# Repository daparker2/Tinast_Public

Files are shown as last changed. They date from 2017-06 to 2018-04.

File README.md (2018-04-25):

## [Newest release works with 5" backpack type HDMI displays](https://github.com/daparker2/Tinast_Public/releases/tag/v1.0.85.1.18). Here's what it looks like:

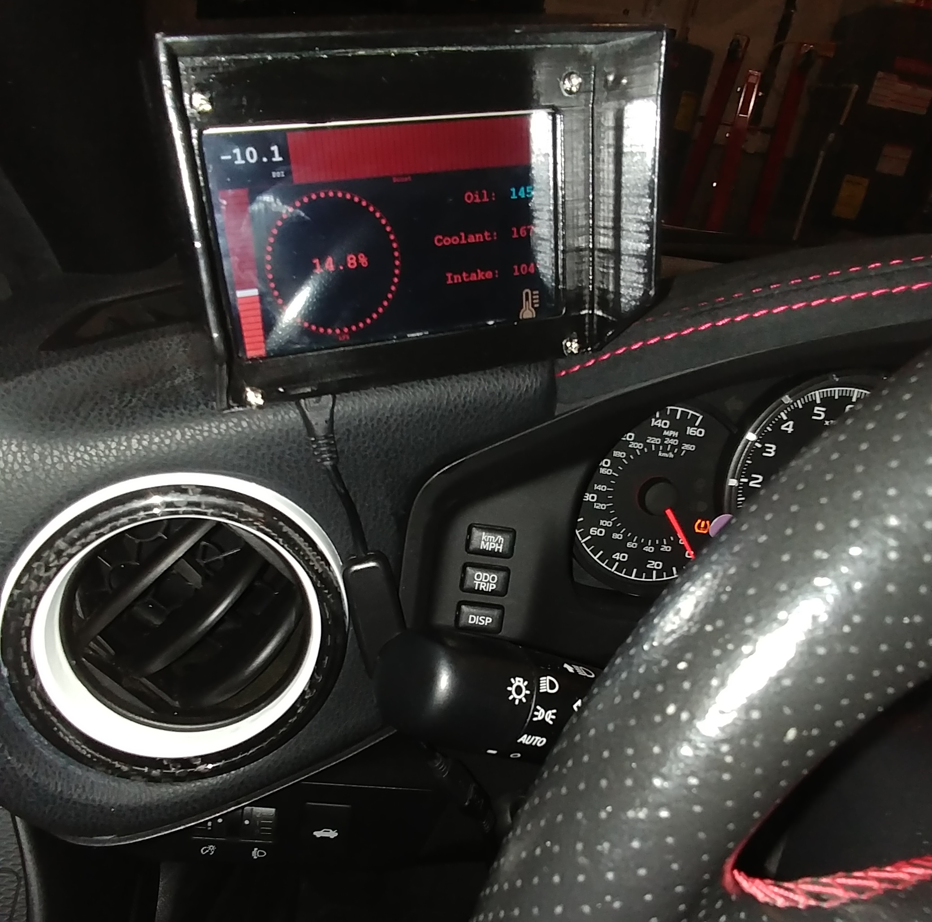
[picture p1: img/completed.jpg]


Also, [3D printable gauge pod model](src/pod.scad).

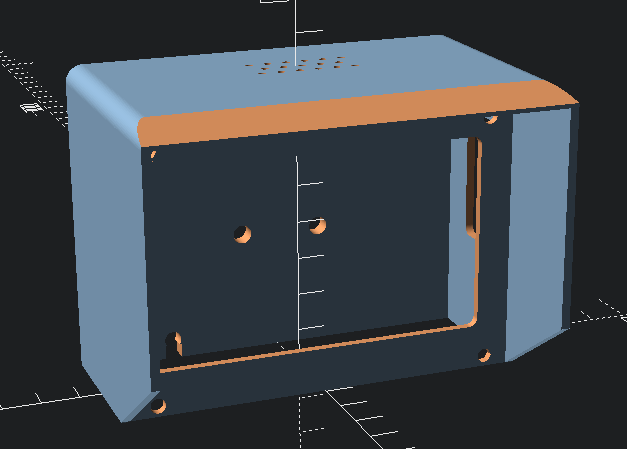
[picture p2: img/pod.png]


Coool.

# Introduction 


This my car dash panel project. It's for my 2013 Subaru BRZ, and the PIDs should work on most BRZ ECUs provided they aren't running OpenFlash, as that changes the oil temp PID. I haven't tested it on other things. I was originally targetting Windows IoT but the Raspberry Pi was having issues staying connected to my OBD2  scantool that were resolved by moving to an intel compute stick. The story for getting an app launched automatically on Windows is more complicated, but can be achieved by adding a scheduled task to the system.

There will be some limited customization of PIDs in a json file (look at displayConfiguration.json for an example) that can be placed in the user settings for the app, but not much in the way of configuring settings for a custom vehicle. I may also add an in-app settings page (in-app interactivity is mostly non existant at this point, as the touch screen didn't even work on my Raspberry).

[HockeyApp](https://rink.hockeyapp.net/manage/apps/553566)

## Update 3: Here's a brief demo of the gauge panel during normal driving

update3 (https://youtu.be/lsFMVJhmXTw "Demo")

## Installation

See [this link](https://htmlpreview.github.io/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) for installation and bringup instructions of a Raspberry Pi bearing this app.

[Click here](https://github.com/daparker2/Tinast_Public/blob/master/Face-Template.psd) to view the mechanical template I used to create my gauge face (PSD).

## Specs

There's some early specs in the wiki folder that could serve as documentation for the interface. Some of the things there are out of date. For example, the early color scheme I selected was too dim on my display so I selected an even higher contrast one.

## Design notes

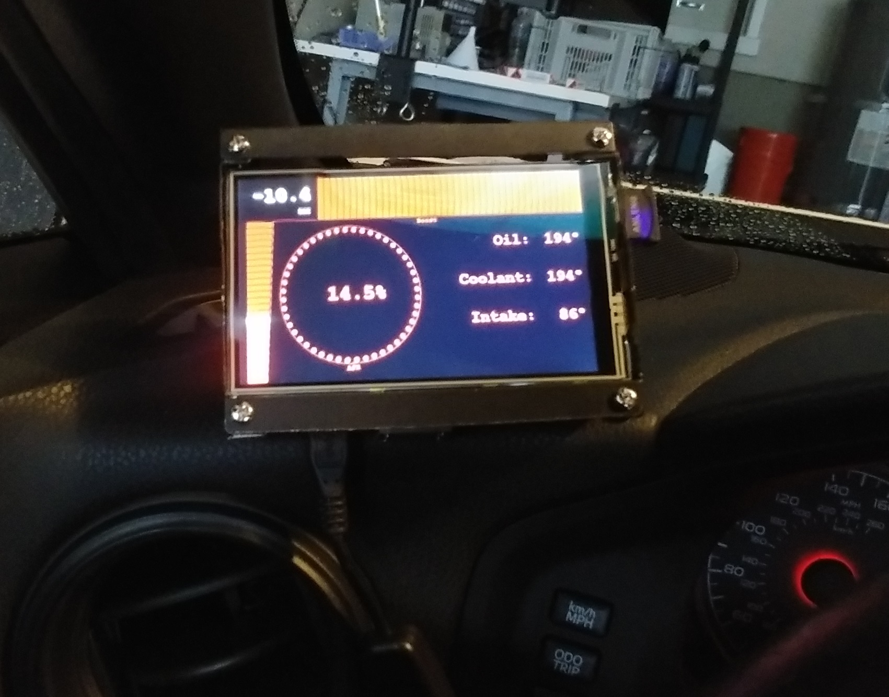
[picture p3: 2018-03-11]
img/update2.jpg

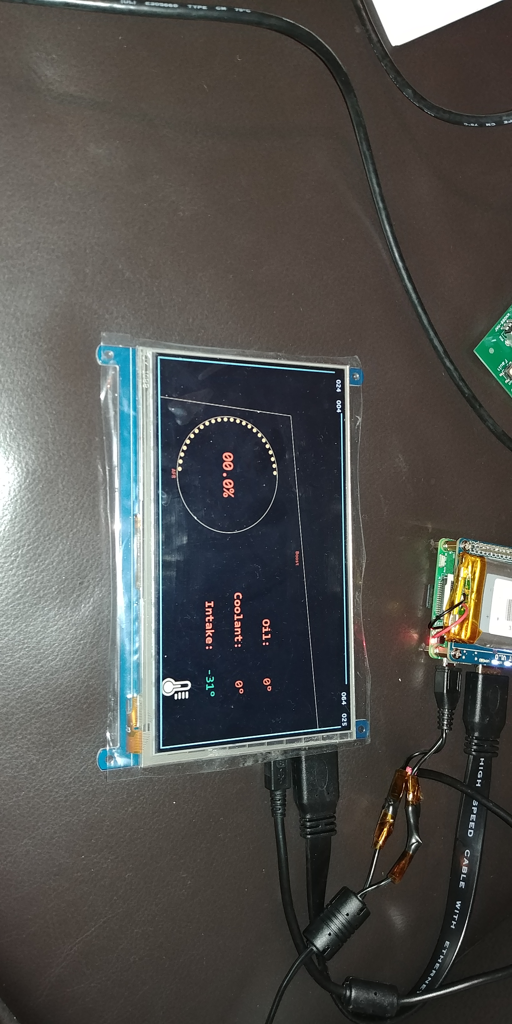
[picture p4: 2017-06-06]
img/update1.jpg

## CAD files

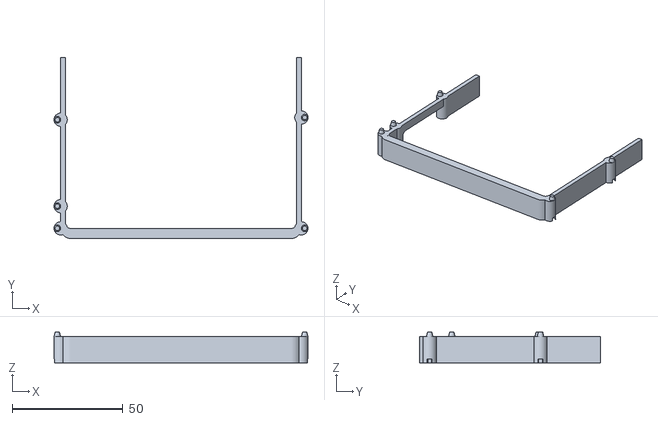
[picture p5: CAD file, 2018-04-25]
src/pod3.stl
114.6 x 81.7 x 14.0

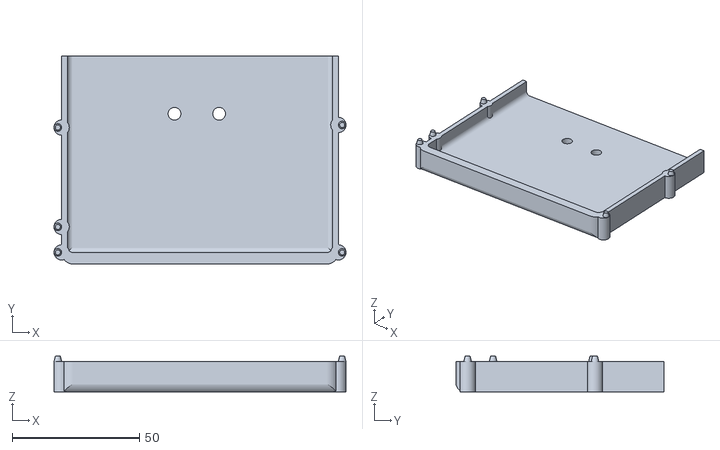
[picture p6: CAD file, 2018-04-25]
src/pod1.stl
114.6 x 81.7 x 14.0

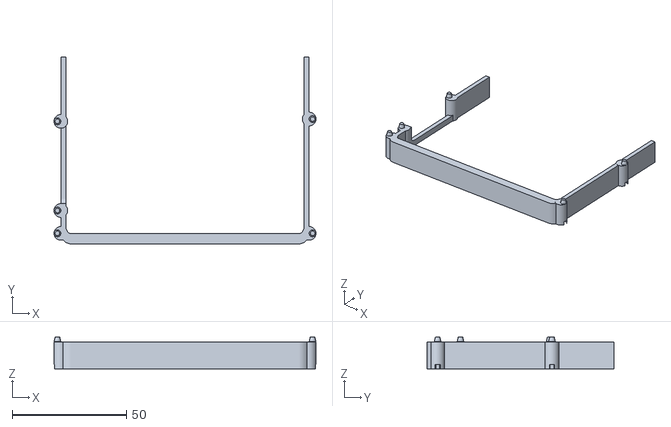
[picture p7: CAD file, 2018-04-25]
src/pod2.stl
114.6 x 81.7 x 14.0

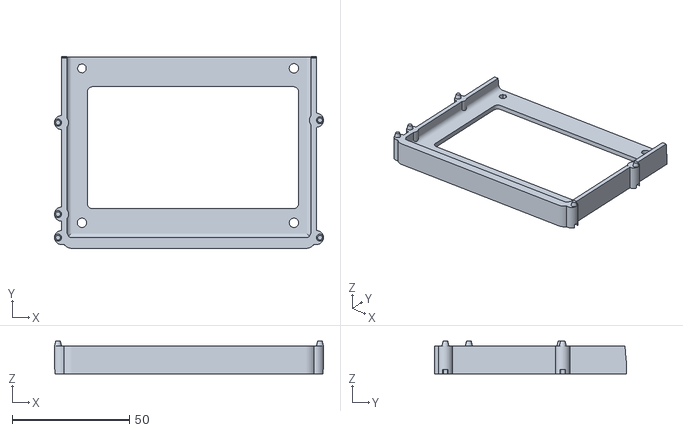
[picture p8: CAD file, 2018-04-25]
src/pod4.stl
114.6 x 81.7 x 14.0

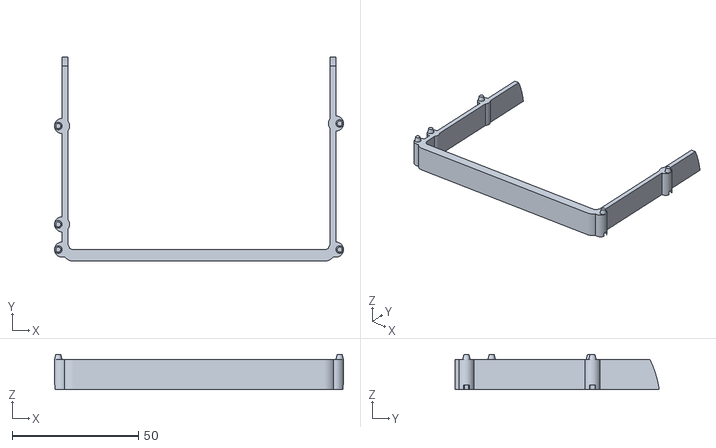
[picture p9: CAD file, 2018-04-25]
src/pod5.stl
114.6 x 81.0 x 14.0

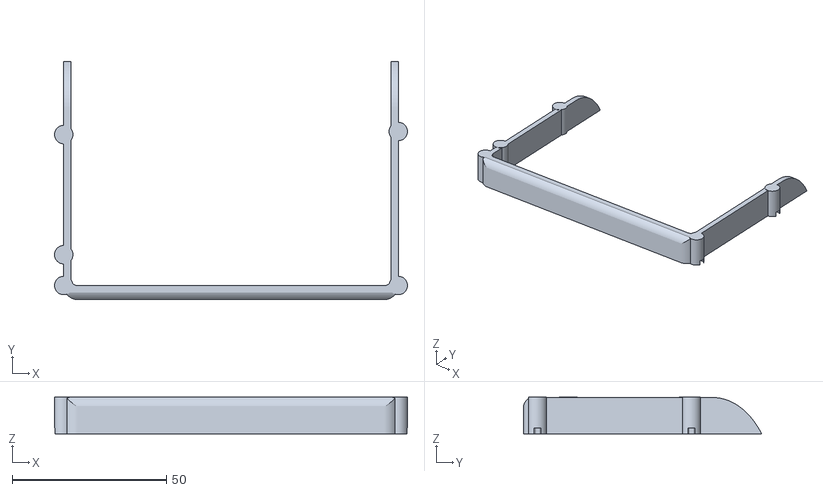
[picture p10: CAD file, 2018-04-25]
src/pod6.stl
114.6 x 77.4 x 11.9

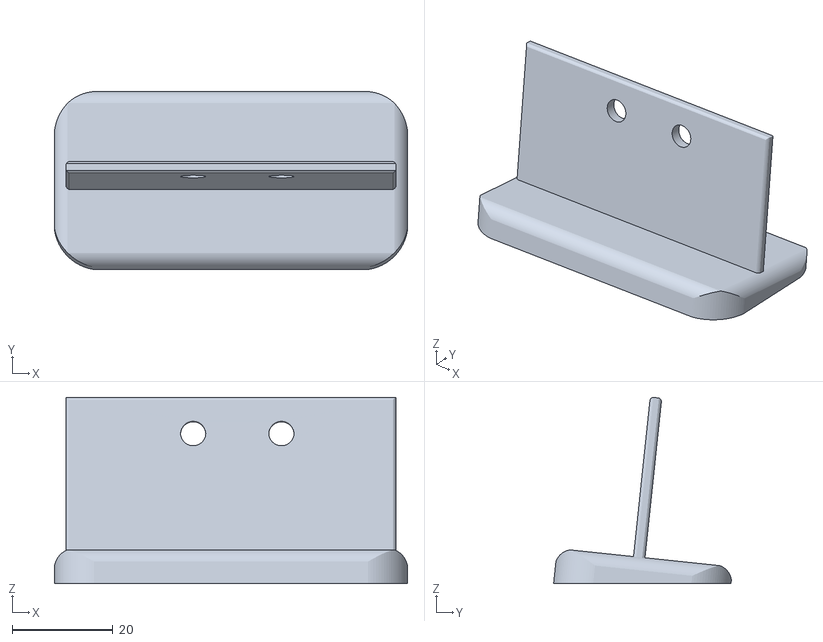
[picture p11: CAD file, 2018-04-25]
src/base.stl
70.0 x 35.3 x 36.9

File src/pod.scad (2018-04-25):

// 3D printable gauge pod for the 4" display setup. We'll break it into 2 major pieces:
// The top and bottom. The top is the "hat" and "roof", the bottom houses the Pi.

// Then the bottom is subdivided into left & right sides and a front and back. There is no
// bottom on the bottom since the Pi goes into the housing thru there.

// FIXMEFIXME: When done, digest this file and try to understand how to more methodically design things for printing in this language. This listing is probably unreadable at this point.

thickness=2.3;
overall_width=104;
// Height doesn't include the size of the top...
overall_height=77;
overall_length=39;
overhang_height=20;
cutout_top = 13;
cutout_left = 10;
cutout_width = 33;
cutout_height=14;
hat_length=30;
hole_pitch = 20;
hole_base = 20;
base_width = 70;
base_height=7;
base_length = 35;
base_angle = 6;
hole_radius = 2.5;
post_radius = 3;
post_height = overall_length + hat_length + thickness;
detail=100;
num_slices=6;

module rounded_corner(x, y, z, r)
{
	difference() {
		cube([x, y, z]);
		translate([r / 2 - .05, r / 2 - .05, 0]) {
			minkowski() {
				cube([x - r + .1, y - r + .1, z]);
				sphere(r=r / 2, $fn=detail);
			}
		}
	}
}

module half_rounded_corner(x, y, z, r)
{
	difference() {
		rounded_corner(x, y, z, r);
		translate([-x / 2, -y / 2, -z / 2])
			cube([2 * x, y, 2 * z]);
	}
}

module post(radius, height, bottom, top, left, right) {	
	union() {
		difference() {
			cylinder(r=radius, h=height, $fn=detail);
			if (bottom) {
				translate([right ? radius / 2 : -radius / 2,0,height - 1.9])
					cylinder(r2=radius/1.75, r1=radius/1.75, h=2, $fn=detail);
			}
		}
		if (top) {
			translate([right ? radius / 2 : -radius / 2,0,-2.1])
				cylinder(r2=radius/2, r1=radius/2-.5, h=2, $fn=detail);
		}
	}
}

module top(width,height) {
	vent_size=1.75;
	vent_x = 5;
	vent_y = 5;
	
	union() {
		difference() {
			union() { 
				translate([thickness, -thickness, 0]) 
					cube([width - 2 * thickness, height + hat_length + thickness, 2 * thickness]);
				translate([thickness, height + hat_length, 0]) 
					rotate([90, 0, 0]) 
					cylinder(r=2 * thickness, h=height + hat_length + thickness, $fn=detail);
				translate([width - thickness, height + hat_length, 0]) 
					rotate([90, 0, 0]) 
					cylinder(r=2 * thickness, h=height + hat_length + thickness, $fn=detail);
			}		
			translate([-thickness, -thickness, -(2 * thickness)]) 
				cube([width + 2 * thickness, height + hat_length + 2 * thickness, 2 * thickness]);
			
			translate([-thickness, -2.8, -66.6])
				rotate([90, 0, 90])
					half_rounded_corner(height + hat_length + thickness + 1, height + hat_length + thickness, width + 2 * thickness, 4 * thickness);
		}
	}
}

module overhang(width, height) {
	overhang_length=overall_height - height;
	union() {
		translate([-.1,-width + .1]) 
			cube([overhang_length,width,thickness]);
			translate([overhang_length,0]) 
				rotate([180, 0, 0]) 
					translate([-.1,-.1,-thickness])
						difference() {
							scale([min(width, height) / max(width, height), 1, 1])
								linear_extrude(height=thickness) 
									circle(r=max(width, height), $fn = detail);
							
							translate([ - overhang_length, -width, -.1])
								cube([overhang_length,width,thickness + .2]);
						}
	}	
}

module right(width, height) {
	
	union() {
		difference() {
			cube([height + .1, width + thickness, thickness]);
			translate([cutout_top + thickness, cutout_left + thickness, -(2 * thickness)]) 
				minkowski() {
					cube([cutout_width - thickness, cutout_height - thickness, 4 * thickness]);
					sphere(r=thickness, $fn=detail);
				}
		}
		overhang(hat_length, overhang_height);
	}
}

module left(width, height) {
	union() {
		cube([height + .1, width + thickness, thickness]);
		overhang(hat_length, overhang_height);
	}
}

module back(width,height) {
	hole_pitch = 20;
	hole_base = 20;
	hole_x = (width - hole_pitch) / 2;
	hole_y = height - hole_base - hole_radius;
	difference() {
		cube([height + .2, width, 2 * thickness]);
		translate([hole_y,hole_x,-(thickness)]) 
			cylinder(r=hole_radius,h=4 * thickness, $fn=detail);
		translate([hole_y,hole_x + hole_pitch - hole_radius,-thickness]) 
			cylinder(r=hole_radius,h=4 * thickness, $fn=detail);
	}
}

module front(width,height) {
	display_x = 3 + thickness;
	display_y = 10 + thickness;
	display_width = 90 - thickness;
	display_height = 52 - thickness;
	hole_width = 92 + thickness;
	hole_height = 53.5 + thickness;
	
	hole_radius = 2;
	hole_offset = 5;
	
	difference() {
		cube([width,height,thickness]);
		translate([display_x + thickness,display_y + thickness,-(2 / thickness)])
			minkowski() {
				cube([display_width - thickness,display_height - thickness,2 * thickness]);
				sphere(r=thickness, $fn=detail);
			}
		
		// Add mounting holes...
		translate([display_x + hole_radius,display_y - hole_offset - 1,-(2 / thickness)])
			cylinder(r=hole_radius, h=2 * thickness, $fn=detail);
		translate([display_x + hole_width - hole_radius,display_y - hole_offset - 1,-(2 / thickness)])
			cylinder(r=hole_radius, h=2 * thickness, $fn=detail);
		translate([display_x + hole_radius,display_y + hole_height + hole_offset - 1,-(2 / thickness)])
			cylinder(r=hole_radius, h=2 * thickness, $fn=detail);
		translate([display_x + hole_width - hole_radius,display_y + hole_height + hole_offset - 1,-(2 / thickness)])
			cylinder(r=hole_radius, h=2 * thickness);
	}
}

module base(hole_pitch, hole_base, base_width, base_height, base_length, base_angle)
{
	hole_radius = 2.5;
	bh = base_height * sin(base_angle);
	union() {
		difference() {
			cube([base_width, base_length, base_height]);
			translate([-.05, -.05, -.05])
				rounded_corner(base_width + .1, base_length + .1, base_height + .1, 8 * thickness);
			translate([-.05, -.05, -.05])
				rotate([90, 0, 90])
					half_rounded_corner(base_length + .1, base_height + .1, base_width + .1, base_height);
			translate([-.05, base_length -.05, -.05])
				rotate([90, 0, 0])
					half_rounded_corner(base_width + .1, base_height + .1, base_length + .1, base_height);	
				rotate([base_angle, 0, 0])
					translate([-1,-1,-20])
						cube([base_width + 2, base_length + 2, 20]);	
		}
		
		translate([thickness, base_length / 2, base_height - .1])
			rotate([90,0,0])
				difference() {
					cube([base_width - 2 * thickness, hole_base + 2 * hole_radius  + 3 * thickness, thickness]);
					translate([-0.05,hole_base + 2 * hole_radius + 3 * thickness + 0.05, -0.05])
						rotate([90,0,0])
							rounded_corner(base_width - 2 * thickness + .1, thickness + .1, hole_base + 2 * hole_radius + 3 * thickness + .1, thickness); 
					
					// Add speed holes...
					#translate([(base_width - 2 * thickness - hole_pitch) / 2 + hole_radius,hole_base + hole_radius + base_height,-base_length / 2]) {
						
		translate([0,-hole_radius - thickness,-overall_length / 2 + thickness]) 
			cylinder(r=hole_radius,h=overall_length, $fn=detail);
		translate([0 + hole_pitch - hole_radius,-hole_radius - thickness,-overall_length / 2+ thickness]) 
			cylinder(r=hole_radius,h=overall_length, $fn=detail);
					}
					
					translate([-thickness,-thickness - .7,thickness + .05])
						rotate([0,90,0])
							half_rounded_corner(thickness + .1, base_length, base_width, thickness);
			}
	}
}

module podule_buttresses(buttress_height, bottom, top) {
	rotate([90,0,0]) translate([0,0,-overall_length - hat_length]) {
		translate([-thickness,0,0])
			post(post_radius, buttress_height, bottom, top, true, false);
		translate([overall_width + thickness,0,0])
			post(post_radius, buttress_height, bottom, top, false, true);
		translate([overall_width + thickness,-50,0])
			post(post_radius, buttress_height, bottom, top, false, true);
		translate([-thickness,-cutout_top + post_radius,0])
			post(post_radius, buttress_height, bottom, top, true, false);
		translate([-thickness,-cutout_top - cutout_width - post_radius,0])
			post(post_radius, buttress_height, bottom, top, true, false);
	}
}
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

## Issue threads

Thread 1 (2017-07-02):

Mock the ELM 327 driver

daparker2, 2017-07-02:
Mock the ELM 327 driver against the UI to make sure UI stuff doesn't break.

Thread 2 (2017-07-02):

Mock the UI

daparker2, 2017-07-02:
Mock the UI against a fake ELM 327 driver to make sure the driver code doesn't get broken.

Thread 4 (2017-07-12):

The app has a "dead man's switch" to automatically reboot the system

daparker2, 2017-07-12:
To workaround an unknown issue with the bluetooth adapter communicating with the scan tool, the system has a dead man's switch to automatically reboot the system.

This is a bad idea, but necessary so that it continues to run without user interaction.

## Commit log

2017-05-25 Added file config.txt for the dang Raspberry Pi
    [config.txt]
2017-05-26 This my car dash panel project. It's for my flashed ECU 2013 Subaru BRZ. It probably won't work on anything else. The LCD has a touchscreen, but Windows IoT won't support the nonstandard 1024x600 res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
    There will be some limited customization of PIDs in a json file, but probably no way to deploy changes there without branching. There might be limited datalogging but we're pretty much a long way from that.
    1. Raspberry Pi 3
    2. Raspi UPS Hat
    3. Waveshare 7 inch LCD
    4. ScanTool OBD MX
    I modified the Raspi to power the unit on automatically on ignition. The LCD backlight is also turned on at ignition (it's not on the UPS system).
    The UP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
2017-05-30 Created page Required PIDs
    [Required-PIDs.json]
2017-06-01 Updated page Required PIDs
    [Required-PIDs.json]
2017-06-01 Start working on the display viewmodel. Still need a dang ELM 327 driver implementation though.
    Related Work Items: #2
2017-06-01 Start working on the dang old OBD2 driver.
    Related Work Items: #1
2017-06-01 Add the rest of the PIDs for the Elm 327 driver
    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
2017-06-02 Finish up (hopefully) with the ELM 327 driver, and make the display view model a bit easier to read.
    Related Work Items: #1, #2
2017-06-03 Add stubs for the gauge controls. Also improve the ELM 327 driver by waiting for exactly as many responses as it expects, as well as creating a handler table for PID requests.
2017-06-03 Lay out the gauges on the main display, and add some properties to the temperature gauge.
2017-06-05 Pipeline the property changed notifications with the ELM327 read. Also, add the temperature control and a MIL for temperature warnings. Improve the timing of the MIL blink somewhat.
    Related Work Items: #2, #6, #7, #8
2017-06-10 Give AFR, Boost, and temperature controls a shared animation timer.
2017-06-11 Fix a bug that was preventing the auto reconnect from working, as well as checking in my most up to date config.txt.
    Include the displayConfiguration.json with the package.
    [config.txt]
2017-06-13 Sort of get his working on my car. Need to make some tweaks though; Oil temp pid isn't reporting Also boost isn't totally being computed correctly; need to subtract atmospheric pressure from manifold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
2017-06-14 Various changes and bugfixes; the oil temp PID should work now, as well as proper idle load detection. Fix an issue preventing the app from working on a Desktop UWP system.
2017-06-15 Fix the oil PID read, as well as fix a few UI issues. Adjust the AFR readout so 14.7 is perfectly centered instead of slightly offset.
2017-06-17 Fix the template to add a couple strain relief tabs on the top and fix the boost control flashing behavior, as well as the boost offset configuration.
    Fix a few of the bullshit problems which occured when launching this app on a desktop system.
2017-06-24 Fix the boost gauge so it reports boost pressure accurately as well as indicating the boost pressure more responsively on the gauge face.
    Related Work Items: #11
2017-06-25 Deleted wiki
    [Required-PIDs.json]
2017-07-02 A few tweaks and changes to the async calls in the tool, as well as some minor bugfixes.
    Add a bringup guide to the doc folder.
    [config.txt]
2017-07-02 Changes to gauge flash to makes work more gooder with low power devices, such as the Raspberry Pi.
2017-07-08 To counteract some of the apparent instability in the bluetooth adapter, add a dead man's switch to the update state machine which will give the user a 5 second warning before automatically system, i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
2017-07-26 So basically the visual studio test runner doesn't work good with Xunit. So use the Xunit devices runner instead, which gives you a nice UI to launch tests from.
    Issue: 1
2017-07-27 Add a couple theories about our config class.
    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
2017-07-28 Break apart the Elm 327 driver and Elm 327 connection into separate classes. This is so we can test the connection and driver independently.
    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
2017-07-29 Layout fixes and don't unpair the BT device programmatically.
2017-08-03 Just a bunch of changes to qualify this on my Raspberry Pi setup with the CSR bluetooth dongle. Basically:
    - Permit unit tests to throw once when interacting with the scantool, provided they don't throw the same exception successively.
    - Refactor method names
    - Reorder methods
    - Simplify OpenAsync in BluetoothElm327 connection
    - Attempt to cleanly cancel blocked IO operations if they don't complete within the specified time.
    - Increase test result timeout
    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
2017-08-03 Add example project for completely breaking the bluetooth stack on a Raspberry Pi.
2017-11-24 Framework update, restore pipelined update behavior and correct gauge display
2018-03-11 Add gauge pod for 4" display version
    [pod-bottom.stl, pod-top.stl, pod.scad]
2018-03-11 Fix commented out thing in scad file and add preview image.
    [pod.scad]
2018-04-25 Various updates for stuff I've been working on - Make the model more ABS printable by allowing it to be sliced into different sections (up to 6) - Fix a bunch of FxCop issues an disable others - Upda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
    [base.stl, pod-bottom.stl, pod-top.stl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]
2018-04-25 Woops. Add more missing stuff from last commit.
    [pod1.stl, pod2.stl, pod3.stl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]
